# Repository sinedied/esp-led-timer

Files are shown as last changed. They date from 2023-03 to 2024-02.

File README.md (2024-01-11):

# ⏰ esp-led-timer

> 64x32 led matrix timer for conferences with remote WiFi control, based on ESP8266/ESP32.

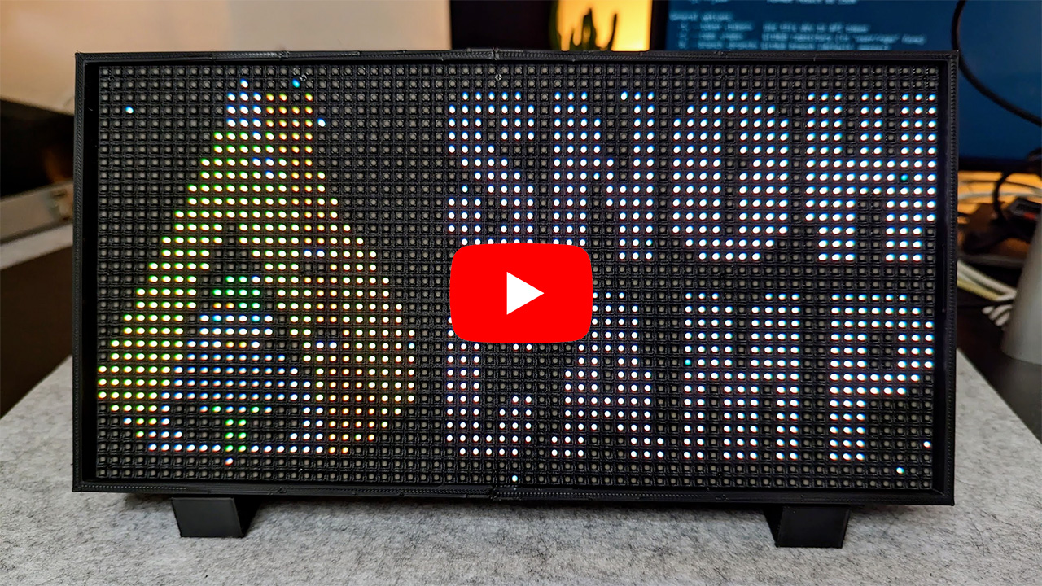
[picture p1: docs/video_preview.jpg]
Demo video (https://youtu.be/CDZh9LY9HXI)


*Note: time countdown is accelerated x100 in the video.*

## Assembly guide

You can find a detailed step-by-step assembly guide [here](./docs/assembly.md).

## Components used
- 64x32 P4 LED Panel [aliexpress](https://aliexpress.com/item/1005004050044228.html)
- ESP32 CH340 Type-C [aliexpress, make sure to pick the right one](https://aliexpress.com/item/1005004616357165.html)
- 2m USB-C cable [aliexpress, make sure to pick the right one](https://aliexpress.com/item/1005004215823904.html)
- 20W USB-C Charger [aliexpress](https://aliexpress.com/item/1005001875465341.html)
- 10cm M-F Dupont Cable 40pin [aliexpress, make sure to pick the right one](https://aliexpress.com/item/1005004073424751.html)
- 10cm F-F Dupont Cable 40pin [aliexpress, make sure to pick the right one](https://aliexpress.com/item/1005004073424751.html)
- 20cm F-F Dupont Cable 40pin [aliexpress, make sure to pick the right one](https://aliexpress.com/item/1005004073424751.html)
- Push button kit [aliexpress](https://aliexpress.com/item/1005005012663073.html)

**Total:** about 30 euros

## Wiring diagram

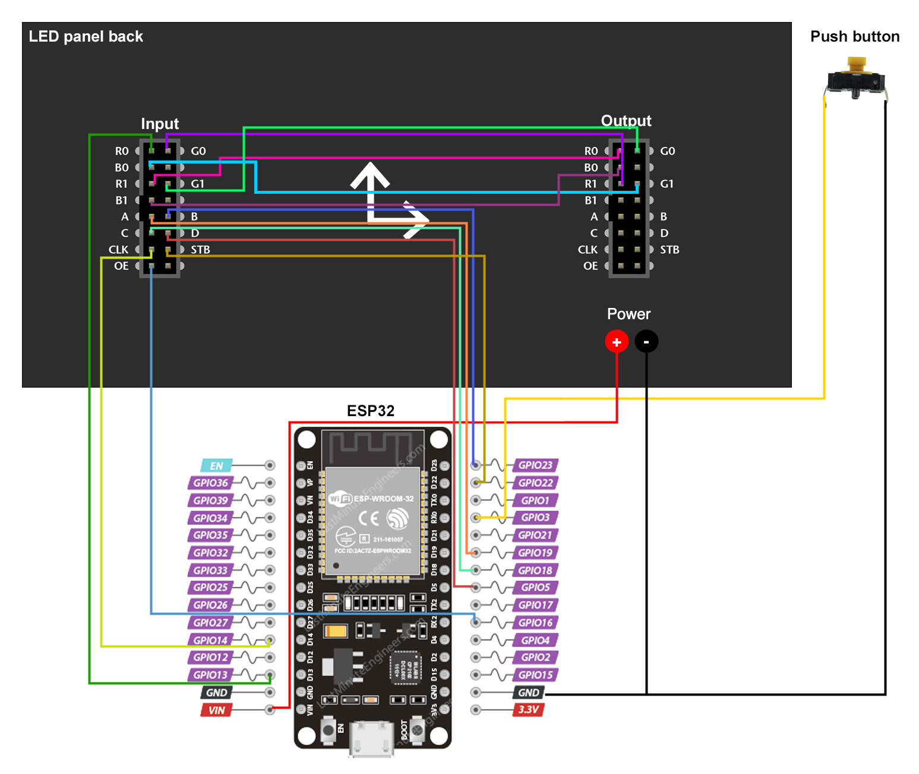
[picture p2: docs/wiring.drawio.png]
Wiring diagram


Connect panel input (PI) and and panel output (PO) like this:

PI | PO
---|---
R1 | R0
G0 | R1
G1 | G0
B0 | G1
B1 | B0

Connect panel input (PI) to the ESP8266 or ESP32 like this:

PI      | ESP8266 GPIO | ESP32 GPIO
--------|--------------|------------
A       |  05 - (D1)   | 19 
B       |  04 - (D2)   | 23 
C       |  15 - (D8)   | 18 
D       |  12 - (D6)   | 5 
STB/LAT |  16 - (D0)   | 22 
P_OE    |  02 - (D4)   | 16 
CLK     |  14 - (D5)   | 14 
R0      |  13 - (D7)   | 13 

Connect push button pins to the ESP8266 or ESP32 like this:

BUTTON | ESP8266 GPIO | ESP32 GPIO
-------|--------------|------------
L      | RX - (D9)    | RX0
R      | GND          | GND

## 3D printed case

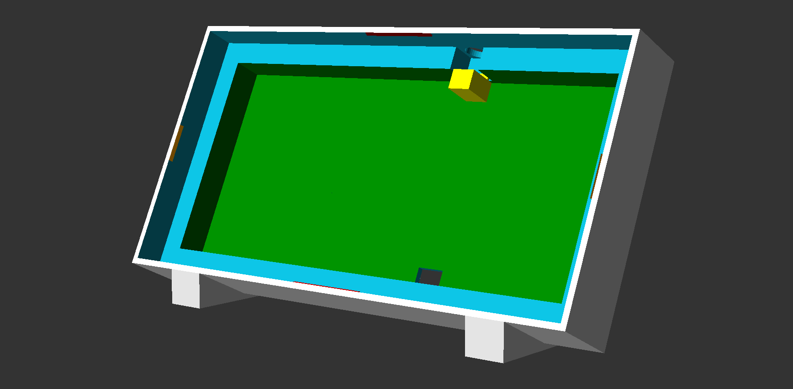
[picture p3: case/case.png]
case preview


You'll find a parameterized case model in `case/case.scad`.

You can customize and compile this file into an STL using [OpenSCAD](https://openscad.org).

I recommend to set `test_print` to true in the customizer ("Other" tab) and first print these test models to test and adapt the `tolerance` value for your printer (higher = more loose fit, smaller = tighter fit).

This model makes use of the BOSL2 library, see [instructions here](https://github.com/revarbat/BOSL2) for how to install it.

## Building project

This project is built using [VS Code](https://code.visualstudio.com/) and [PlatformIO](https://platformio.org/).

Once loaded, Platform IO will download the platform SDK and dependencies automatically, then you'll be able to build and upload the project to your ESP.

> You update the `platformio.ini` file to change the board type and platform, this project is compatible with both ESP8266 and ESP32 boards.

## How to use

- **Push button:** start/stop timer
- **Long press (1s)**: reset timer
- **Double press**: next mode
- **Triple press**: change brightness

Modes cycles between the logo/screensaver and the differents timers.

When the timer is not running, the logo/screensaver will be automatically activated after 5 minutes without touching any button.

### Special commands

- **Hold button for 5s**: enable/disable WiFi AP
- **Hold button for 10s**: reset all settings and reboot
- **5x press**: toggle x100 time acceleration (for demo/testing purposes)

When WiFi is enabled, the device will create an access point with the name "Timer" by default. Connect to it, and you should be presented with a captive portal to control and configure the device.

## Updating bitmaps

To generate the bitmap arrays for images, I used [image2cpp](https://javl.github.io/image2cpp/).
Make sure to set RGB565 format and change the type to `uint16_t static` instead of `const uint16_t`, otherwise the app will crash.

The bitmaps are located in `src/bitmaps.h`.

For drawing the bitmaps I used [PixiArt](https://www.pixilart.com/draw).

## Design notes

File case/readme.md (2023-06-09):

# 3D printed case

case preview

The case of this project is designed to be 3D printed.

You can find ready-to-print STL files in the [stl/](./stl/) folder.
- If you have a 3D printer with a large bed, you can print the case and its support in one piece using the `case_all_nosplit.stl` file.

- Otherwise, you can print the case split in two part and the support separately using the `case_left_part.stl`, `case_right_part.stl` and `case_feet_and_button_lock` files.

The case is designed to be printed with supports, so make sure to enable them in your slicer. Tolerance has been added to the case to make sure the parts fit together nicely, but you'll require a bit of sanding to make it fit perfectly.

To check if the defaut tolerance is good for your printer, you can print the `test_print.stl` file.

### Customizing the case

If you want to customize the case to adjust the tolerance or support angle for example, you need to use [OpenSCAD](https://openscad.org) and install the BOSL2 library. See [instructions here](https://github.com/revarbat/BOSL2) for how to install it.

Then open the `case.scad` file in OpenSCAD and adjust the parameters in the `Customizer` tab. Once you're happy with the result, select `Render` and then `Export as STL...` to export the STL file.

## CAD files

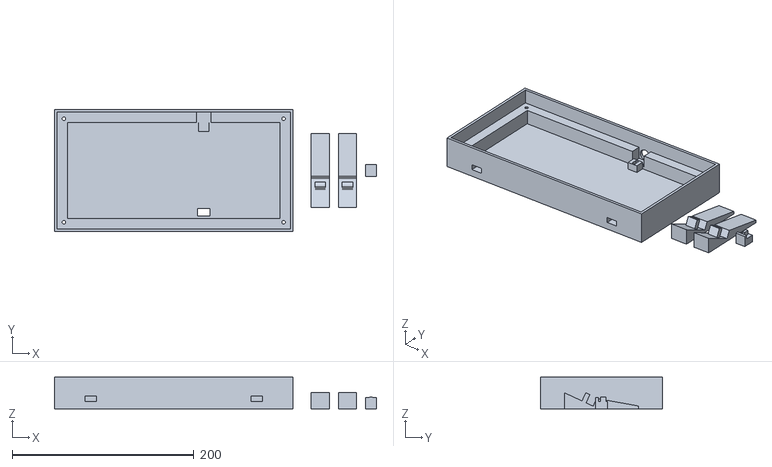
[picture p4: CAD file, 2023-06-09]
case/stl/case_all_nosplit.stl
354.7 x 134.7 x 35.0

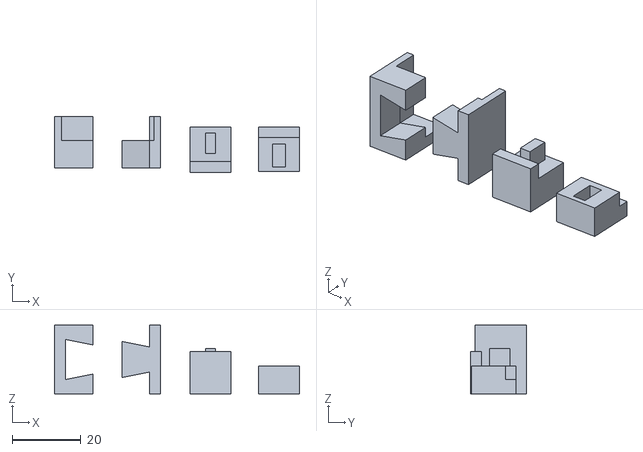
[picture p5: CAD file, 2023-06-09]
case/stl/test_print.stl
71.5 x 16.2 x 20.0

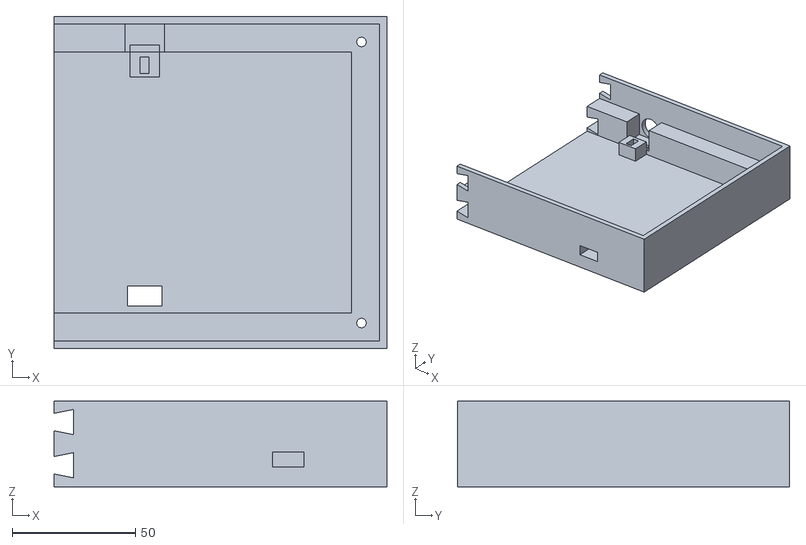
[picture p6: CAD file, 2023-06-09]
case/stl/case_right_part.stl
135.1 x 134.7 x 34.7

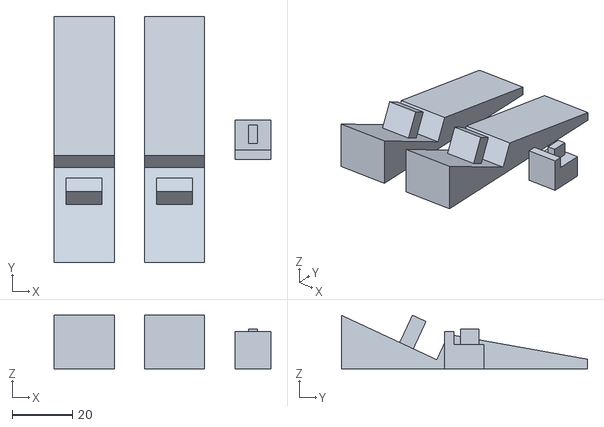
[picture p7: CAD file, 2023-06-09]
case/stl/case_feet_and_button_lock.stl
72.0 x 81.7 x 17.8

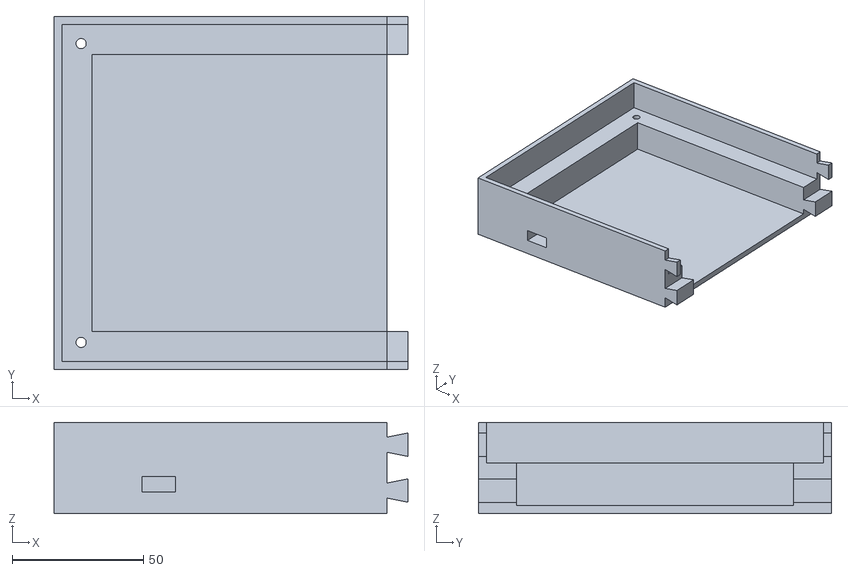
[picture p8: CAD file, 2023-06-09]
case/stl/case_left_part.stl
135.1 x 134.7 x 34.7

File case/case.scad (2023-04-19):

// Compile this file into an STL using OpenSCAD:
// https://openscad.org/

// Requires BOSL2 to be installed, see:
// https://github.com/revarbat/BOSL2
include <BOSL2/std.scad>

/* [Dimensions] ---------------------------------------- */

// LCD panel width
panel_width = 256;

// LCD panel height
panel_height = 128;

// LCD panel depth
panel_depth = 13;

// Wall thickness
wall_width = 3;

// LCD panel back border
inside_border_width = 11.5;

// Space in front of the panel for protection
front_bump = 2;

// Space behind panel for the circuit
circuit_depth = 17;

/* [Hole for usb cable] -------------------------------- */

// Usb hole width
usb_hole_width = 14;

// Usb hole height
usb_hole_height = 8;

// Usb hole centered offset from right side of the panel
usb_hole_offset_x = 95;

// Usb hole centered offset from bottom of the panel
usb_hole_offset_y = 18;

/* [Space and support for button] ---------------------- */

// Push button inner diameter
button_inner_diameter = 11.5;

// Push button outer diameter
button_diameter = 12.8;

// Button switch side width
button_hold_size = 12;

// Space for the button legs and wires
button_side_space = 2;

// Total height of switch + push button (excl. legs)
button_total_height = 12;

// Push button height (excl. switch body)
button_push_height = 8.5;

// Button hole centered offset from right side of the panel
button_offset_x = 95;

// Extra height for button support
button_extra_height = 10;

// Connector width
button_connector_width = 3;

// Connector height
button_connector_height = 6;

// Connector depth
button_connector_depth = 5;

/* [Panel fixation] ------------------------------------ */

// Use screws to fix the panel instead of tabs
use_screws = true;

// Lock tabs thickness
lock_tab_thickness = 0.8;

// Lock tabs base width
lock_tab_size = 20;

// Screw diameter
screw_diameter = 3.2;

// Screw head diameter
screw_head_diameter = 7;

// Screw head depth
screw_head_depth = 5;

// Screw hole position offset from the panel edge
screw_offset = 7;

/* [Angle support] ------------------------------------- */

// Target panel angle
angle = 65;

// Support width
angle_support_width = 20;

// Support extra height
angle_support_extra_height = 50;

// Support min depth
angle_support_min_depth = 3;

// Offset from each side
angle_support_offset_x = 30;

// Connector height
support_connector_height = 5;

// Connector width
support_connector_width = 12;

// Connector depth
support_connector_depth = 10;

/* [Other] --------------------------------------------- */

// Extra space to allow for fit tolerance (reduce for tighter fit)
tolerance = 0.35;

// Fit tolerance for the split parts (reduce for tighter fit)
split_tolerance = 0.25;

// Split case on Y axis instead of Z axis
case_split_y = true;

// Disable case split (if your printer can handle it)
case_no_split = false;

// Left case only
left_case = false;

// Right case only
right_case = false;

// Angle and top button supports only
support_and_button = false;

// Show model with assembled pieces (NOT FOR PRINTING!)
final_view = false;

// Test prints, for checking fit and tolerance value
test_prints = false;

/* [Hidden] */

fudge = .001;
sep = 10;

total_width = panel_width + tolerance*2 + wall_width*2;
total_height = panel_height + tolerance*2 + wall_width*2;
total_depth = panel_depth + circuit_depth + front_bump + wall_width;

panel_hole_width = panel_width + tolerance*2;
panel_hole_height = panel_height + tolerance*2;
panel_hole_depth = panel_depth + tolerance*4 + front_bump;

final_circuit_depth = total_depth - panel_hole_depth + tolerance*2 - wall_width;

final_usb_offset_x = panel_width/2 - usb_hole_offset_x;
final_usb_offset_y = -panel_height/2 + usb_hole_offset_y;
final_usb_depth = wall_width + tolerance*2;

button_hole_width = max(button_hold_size + button_side_space*2, button_diameter + tolerance*2);
button_hole_height = inside_border_width + fudge;
button_hole_depth = button_diameter + tolerance*2;
button_ext_diameter = button_inner_diameter + tolerance*2;

final_button_hole_offset_x = panel_width/2 - button_offset_x;
final_button_hole_offset_y = panel_height/2 + tolerance - inside_border_width + button_hole_height/2 - fudge;
final_button_hole_offset_z = total_depth - panel_hole_depth + tolerance*2 - button_hole_depth + fudge;

button_holder_width = button_hold_size;
button_holder_height = button_hole_height - button_push_height + button_extra_height;
button_holder_depth = final_circuit_depth;
button_holder_offset_y = -button_holder_height/2 + panel_hole_height/2 - button_push_height;

button_support_height = button_total_height - button_push_height;

button_support_depth = button_holder_depth - button_hole_depth + (button_diameter - button_hold_size);
button_support_cut_depth = button_holder_depth - button_support_depth;

angle_height= total_depth * sin(angle);
angle_depth = sqrt(pow(total_depth, 2) - pow(angle_height, 2));
angle_support_height = angle_height + angle_support_extra_height;
angle_support_depth = angle_depth + angle_support_min_depth;
angle_support_offset_y = angle_support_extra_height/2;

support_left_offset_x = angle_support_width/2 - total_width/2 + angle_support_offset_x;
support_right_offset_x = -angle_support_width/2 + total_width/2 - angle_support_offset_x;
connector_y_offset = angle_support_height/2 - angle_height;

$fa = 10;
$fs = .4;
$vpr = [
  final_view ? 85 : 22.5,
  0,
  final_view ? 65 : 0
];
$vpd = final_view ? 700 : 800;
$vpt = final_view ? [0, 0, total_height/2] : [(angle_support_width + sep*5 + button_holder_width)/2, 0, 0];

// ----------------------------------------------------------

module triangle(size, rot = 0) {
  w = size[0];
  h = size[1];
  d = size[2];
  points = [
    [0, 0],
    [0, d],
    [h, 0],
  ];
  path = [
    [0, 1, 2]
  ];
  rotate([90, 0, 270 - rot])
  translate([-h/2, -d/2, -w/2])
  linear_extrude(w) { 
    polygon(points, path);
  }
}

module lock_tab(width = true, mirror = false) {
  points = [
    [0, 0],
    [0, front_bump],
    [lock_tab_thickness, 0],
  ];
  path = [
    [0, 1, 2]
  ];
  if (width) {
    tab_size = lock_tab_size;
    // tab_size = panel_hole_width;
    color("red")
    scale([1, mirror ? -1 : 1, 1])
    translate([0, 0, front_bump/2])
    rotate([90, 0, -90])
    translate([-lock_tab_thickness/2, -front_bump/2, -tab_size])
    linear_extrude(tab_size*2) { 
      polygon(points, path);
    }
  } else {
    tab_size = lock_tab_size;
    // tab_size = panel_hole_height;
    color("orange")
    scale([mirror ? -1 : 1, 1, 1])
    translate([0, 0, front_bump/2])
    rotate([90, 0, 0])
    translate([-lock_tab_thickness/2, -front_bump/2, -tab_size/2])
    linear_extrude(tab_size) { 
      polygon(points, path);
    }    
  }
}

module lock_tabs() {
  // Top tab
  translate([0, -lock_tab_thickness/2 + panel_hole_height/2 + fudge, total_depth - front_bump])
  lock_tab(true, false);
  // Bottom tab
  translate([0, lock_tab_thickness/2 + -panel_hole_height/2 - fudge, total_depth - front_bump])
  lock_tab(true, true);
  // Left tab
  translate([lock_tab_thickness/2 - panel_hole_width/2 - fudge, 0, total_depth - front_bump])
  lock_tab(false, false);
  // Right tab
  translate([-lock_tab_thickness/2 + panel_hole_width/2 + fudge, 0, total_depth - front_bump])
  lock_tab(false, true);
}

module screws_hole() {
  inner_diameter = screw_diameter + tolerance*2;
  outer_diameter = screw_head_diameter + tolerance*2;
  width_offset = total_width/2 - wall_width - tolerance - screw_offset;
  height_offset = total_height/2 - wall_width - tolerance - screw_offset;

  // Top left
  translate([-width_offset, height_offset, 0]) {
    union() {
      cylinder(total_depth*2 + 1, d=inner_diameter, center=true);

      translate([0, 0, screw_head_depth/2 - fudge])
      cylinder(screw_head_depth, d=outer_diameter, center=true);
    }
  }

  // Top right
  translate([width_offset, height_offset, 0]) {
    union() {
      cylinder(total_depth*2 + 1, d=inner_diameter, center=true);

      translate([0, 0, screw_head_depth/2 - fudge])
      cylinder(screw_head_depth, d=outer_diameter, center=true);
    }
  }

  // Bottom left
  translate([-width_offset, -height_offset, 0]) {
    union() {
      cylinder(total_depth*2 + 1, d=inner_diameter, center=true);

      translate([0, 0, screw_head_depth/2 - fudge])
      cylinder(screw_head_depth, d=outer_diameter, center=true);
    }
  }

  // Bottom right
  translate([width_offset, -height_offset, 0]) {
    union() {
      cylinder(total_depth*2 + 1, d=inner_diameter, center=true);

      translate([0, 0, screw_head_depth/2 - fudge])
      cylinder(screw_head_depth, d=outer_diameter, center=true);
    }
  }
}

module button_hole() {
  diff_diameter = button_hole_depth - button_ext_diameter;
  union() {
    // Button space
    translate([0, -0.5, button_hole_depth/2 + 0.5])
    cube([button_hole_width, button_hole_height + 1, button_hole_depth + 1], center = true);
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

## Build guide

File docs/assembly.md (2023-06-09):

# Assembly guide

This is a step-by-step guide to assemble the project.
After following these steps, you will have a fully working device looking like this:

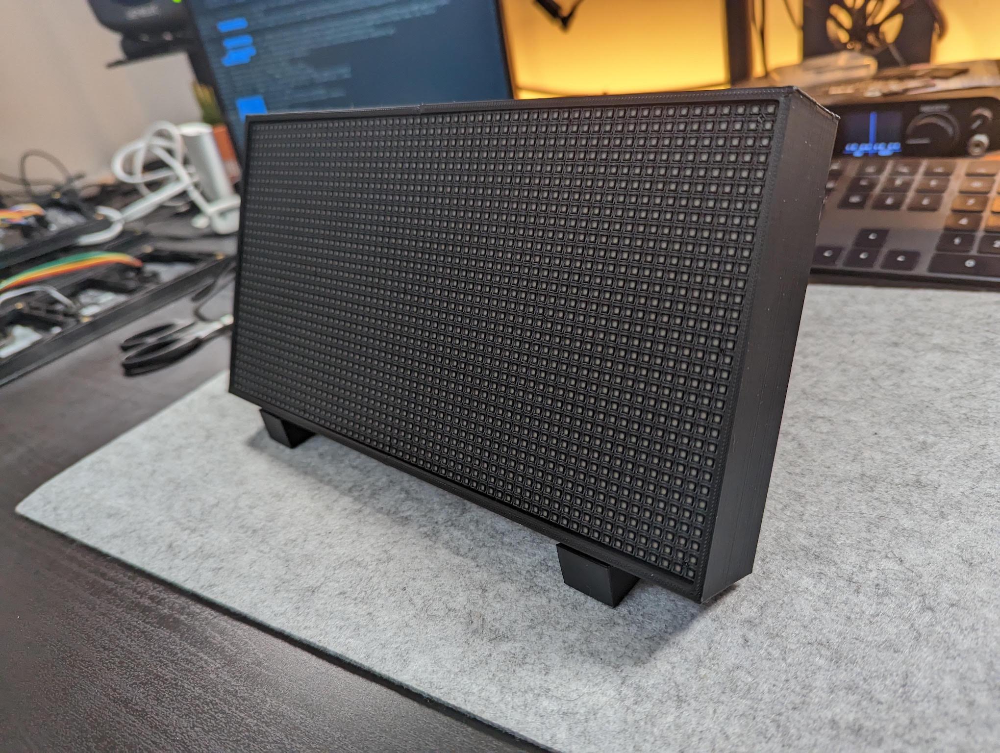
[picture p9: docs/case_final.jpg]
Final result


## Parts and tools needed

Not counting the tools and 3D printed parts, this project costs about 30 euros in parts.

- 1x 64x32 P4 LED Panel [aliexpress](https://aliexpress.com/item/1005004050044228.html)
- 1x ESP32 CH340 Type-C [aliexpress, make sure to pick the right one](https://aliexpress.com/item/1005004616357165.html)
- 1x 2m USB-C cable [aliexpress, make sure to pick the right one](https://aliexpress.com/item/1005004215823904.html)
- 1x 20W USB-C Charger [aliexpress](https://aliexpress.com/item/1005001875465341.html)
- 5x 20cm F-F Dupont Cable 40pin [aliexpress, make sure to pick the right one](https://aliexpress.com/item/1005004073424751.html)
- 8x 10cm F-F Dupont Cable 40pin [aliexpress, make sure to pick the right one](https://aliexpress.com/item/1005004073424751.html)
- 4x 10cm M-F Dupont Cable 40pin [aliexpress, make sure to pick the right one](https://aliexpress.com/item/1005004073424751.html)
- 1x Push button kit [aliexpress](https://aliexpress.com/item/1005005012663073.html)
- 4x M3 20mm screws
- Soldering iron
- Soldering tin
- Electrical tape
- Double sided tape
- Screwdriver

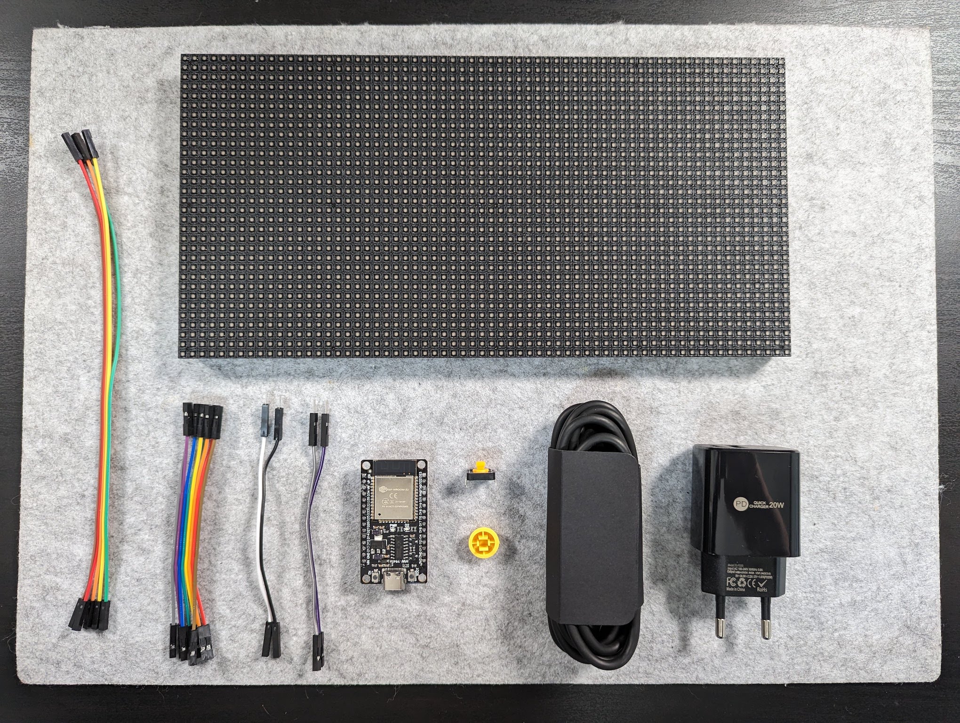
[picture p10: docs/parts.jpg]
Parts


You'll also need to print [the case](../case/) using a 3D printer. If you don't have a 3D printer, you can ask a friend who have one or find a fab lab near your home.

## Soldering the panel power

We'll start by soldering the panel power wires to 10cm M-F Dupont Cables.
Pick 2 10cm M-F Dupont Cables and bend the pins like this:

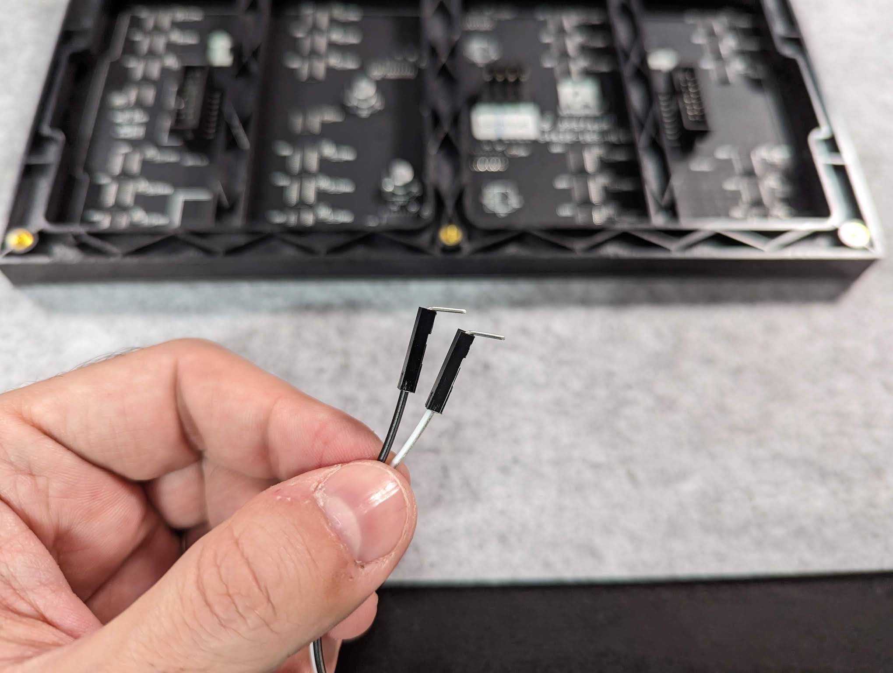
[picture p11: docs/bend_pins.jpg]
Bend pins


Pick the LED panel, and make sure to position it with the arrows pointing up:

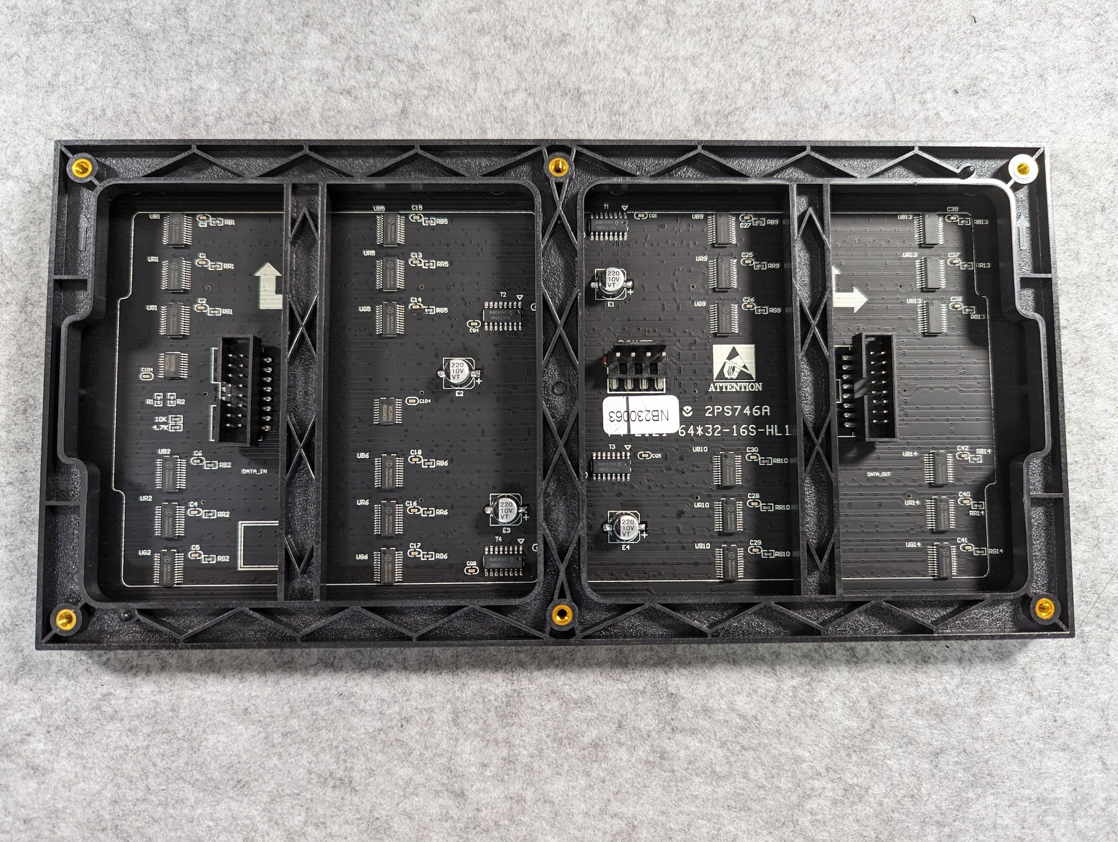
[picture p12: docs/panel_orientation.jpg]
Panel orientation


Then, solder the cables to the panel power wires. The negative wire is the one on the right, and the positive wire is the one on the left:

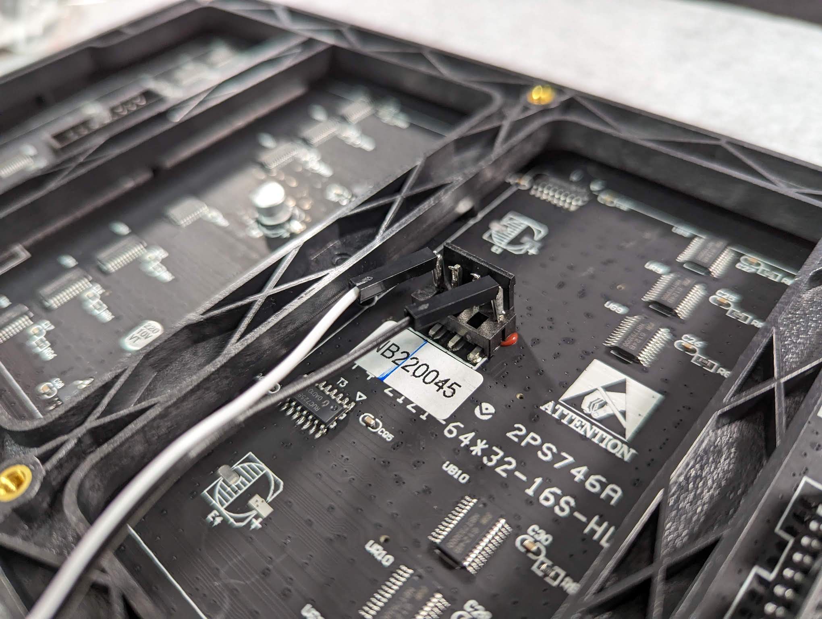
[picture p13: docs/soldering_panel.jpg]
Soldering panel power


## Soldering the button switch

Next we'll solder the button switch to the 10cm M-F Dupont Cables.
Pick 2 10cm M-F Dupont Cables and solder it to the button switch pins on a same side (left or right, it doesn't matter):

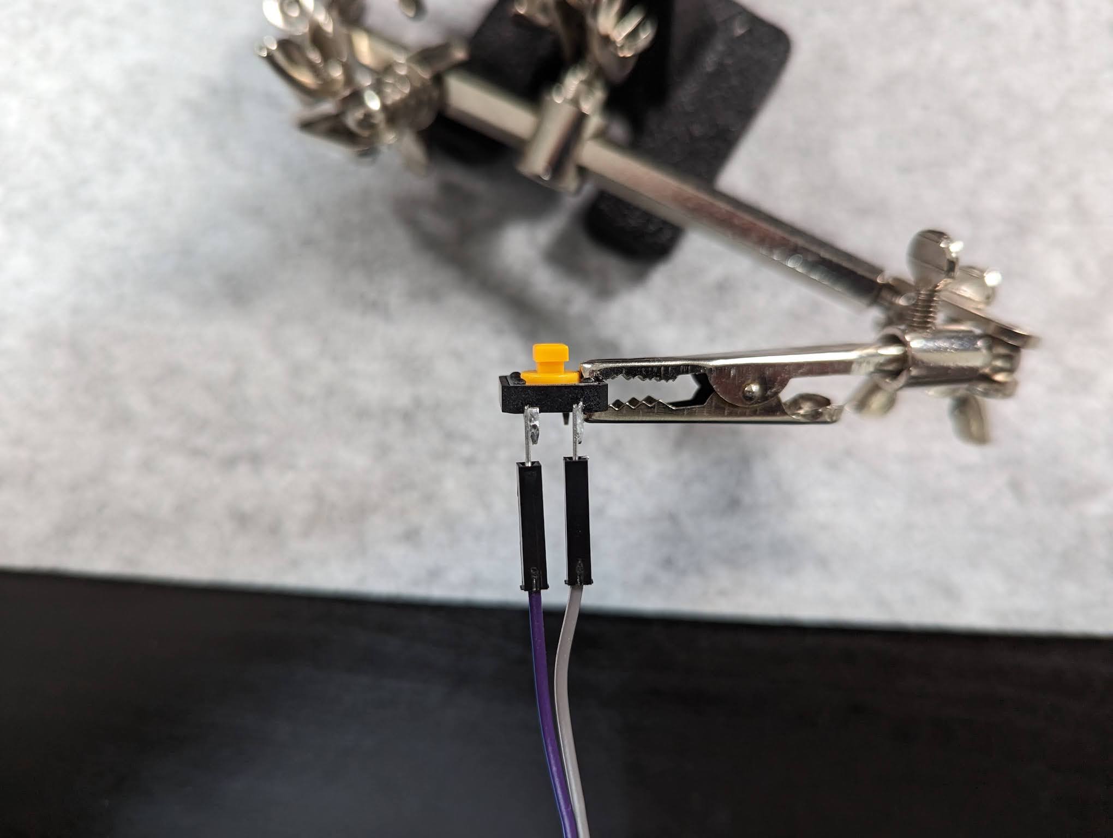
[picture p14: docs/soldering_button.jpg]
Soldering button switch


Position the cable pin and the button pin so that they are aligned side by side, to avoid making a bulge as it would make it harder to fit in the case later.

(And try to do a better job than me at soldering 😆)

## Wiring the panel

Here is the complete wiring diagram:

Complete wiring diagram

We'll first wire the panel inputs (PI) and outputs (PO) together using the 20cm F-F Dupont cables.
Connect panel input (PI) and and panel output (PO) following this table:

PI | PO
---|---
R1 | R0
G0 | R1
G1 | G0
B0 | G1
B1 | B0

The result should look like this:

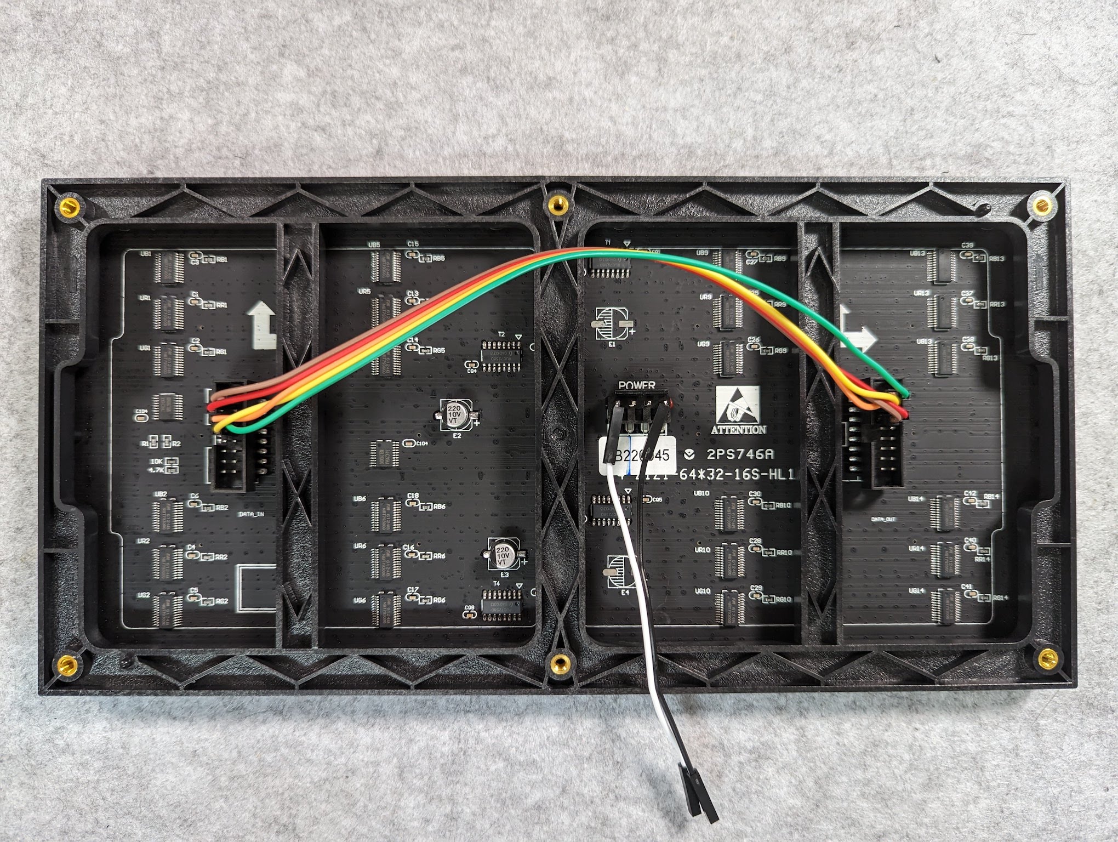
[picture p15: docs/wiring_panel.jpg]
Wiring panel result


## Wiring the ESP32

Pick the 10cm F-F Dupont Cables and connect the ESP32 to the panel following this table:

PI      | ESP32 GPIO
--------|-------------
A       | 19 
B       | 23 
C       | 18 
D       | 5 
STB/LAT | 22 
P_OE    | 16 
CLK     | 14 
R0      | 13 

It's easier to first all the cables to the panel, then to the ESP32. After you're done, connect the button switch to the ESP32:

BUTTON | ESP32 GPIO
-------|-------------
Pin 1  | RX0
Pin 2  | GND

You should end up with something like this:

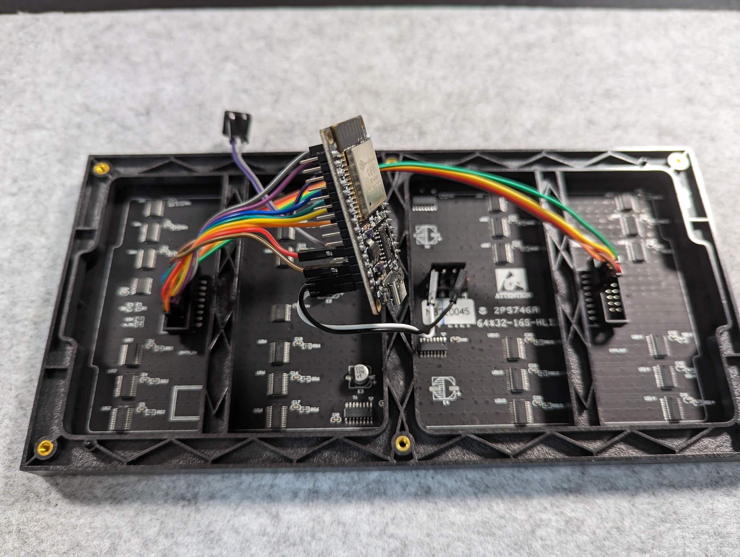
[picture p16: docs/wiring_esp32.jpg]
Wiring ESP32 result


## Uploading the firmware and testing

At this point it is a good idea to test the wiring before going further. To do so, you'll need to upload the firmware to the ESP32.

The easiest it to install [VS Code](https://code.visualstudio.com/) and the [PlatformIO](https://platformio.org/) extension. Follow the [installation guide](https://platformio.org/install/ide?install=vscode) to install both.

Open VS Code and select `Clone Repository`:

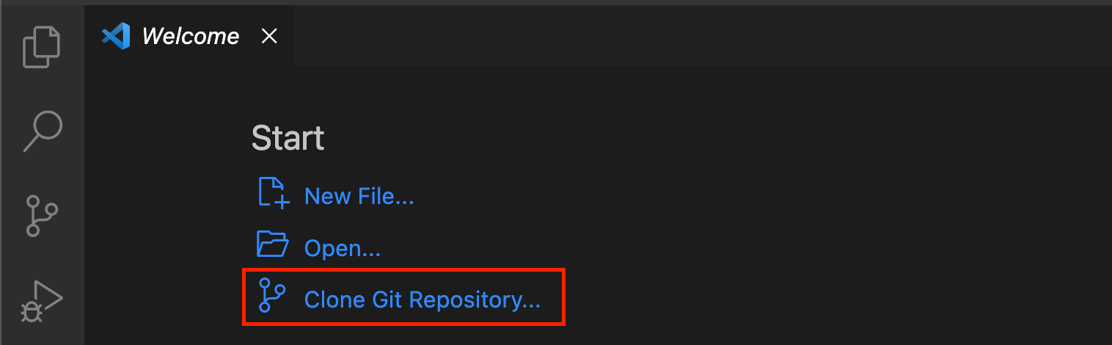
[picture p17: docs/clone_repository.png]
Clone repository


Enter the repository URL `https://github.com/sinedied/esp-led-timer` and select a folder to clone it to. After cloning, select `Open` when prompted.

PlatformIO will take some time to initialize the project and install the dependencies. Once it's done, connect the ESP32 to your computer using the USB-C cable and select the `Upload` button in the status bar:

Upload button in VS Code status bar

The firmware will first compile, then upload to the ESP32. If everything goes well, you should see the following message in the terminal:

```
TODO
```

If your wiring is correct, the LED panel will light up and display the visual manual. Push the button to switch to the timer mode and check that the timer is working.

## Fixing the ESP32 to the case

Now that we know everything is working, we can complete the assembly.

Add some electrical tape on the panel in the top left corner of the section where the ESP32 will be placed, to avoid short circuits:

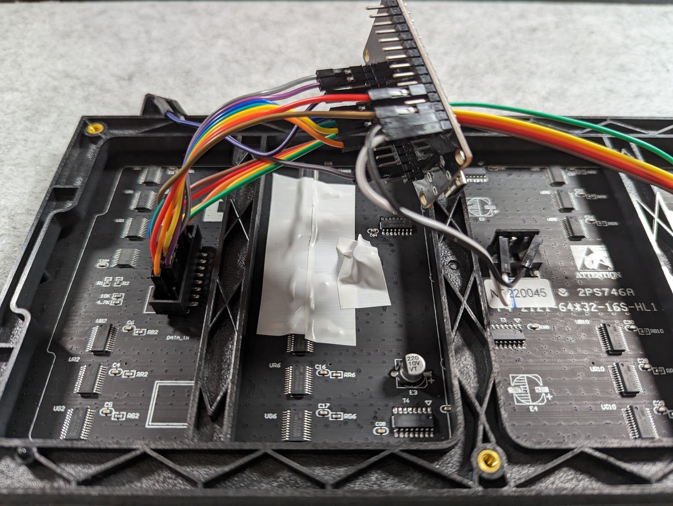
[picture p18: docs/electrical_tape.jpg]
Electrical tape


Then, add some double sided tape on the ESP32 processor and fix it to the case over the electrical tape we just added:

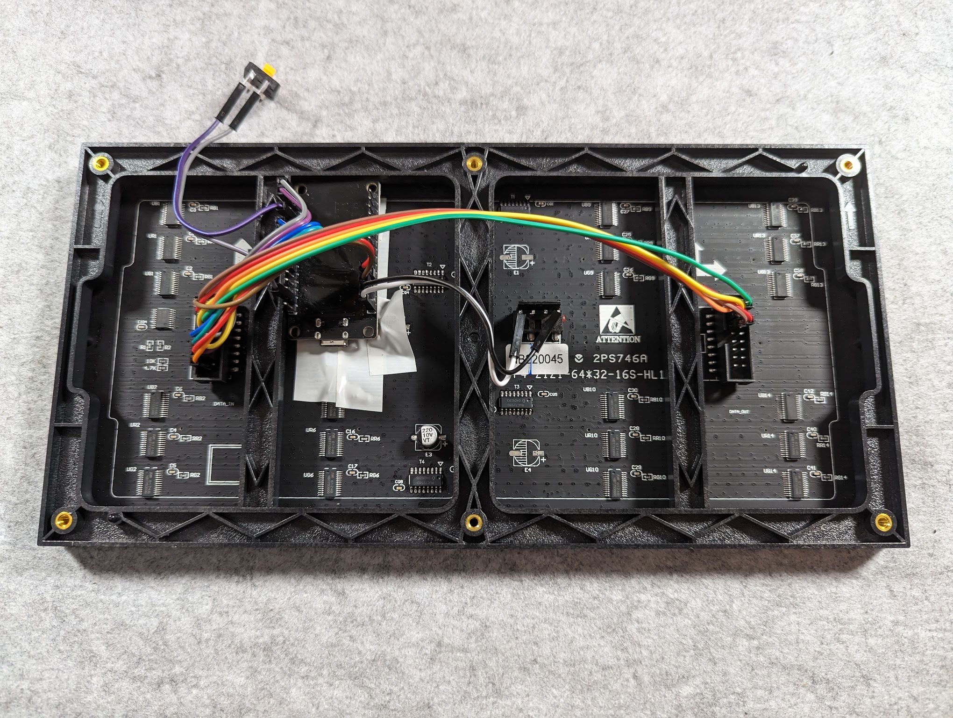
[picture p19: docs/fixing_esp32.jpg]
Fixing ESP32 to the case


Flatten the cables a bit to make it easier to fit in the case.

## 3D Printing the case

The next step is to 3D print the case. You can find the STL files and instructions for printing the case [here](../case/readme.md).

If you printed the case in 2 separate parts, you'll need to assemble the left and right parts together. Don't force too much or you'll break the plastic. If it doesn't fit, try to sand the parts a bit. The fit should be tight so the parts doesn't move, but must fit with only a bit of force.

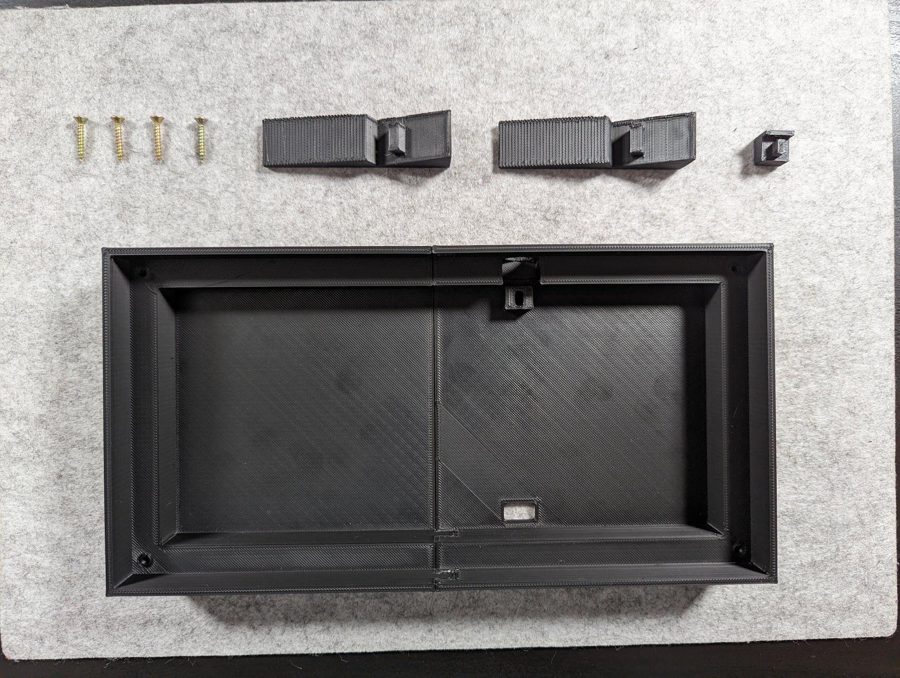
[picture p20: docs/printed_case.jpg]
3D printed case and screws


## Assembling the case

It's time to assemble the case and the electronics.

1. Pass the cables through the hole in the case, from the outside to the inside, and position the button cap from the inside:

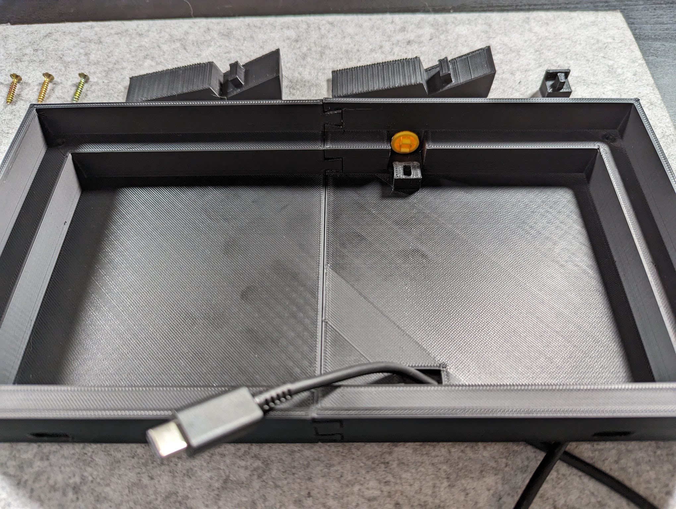
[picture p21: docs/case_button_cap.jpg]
Placing the cable and button cap
   

  The button cap should be sliding without difficulty. If it doesn't, remove it and try to sand the hole a bit.

2. Plug the USB-C cable to the ESP32 without leaving too much cable inside the case.

3. Place the button switch inside the button cap, with the 2 connected pins on the left side of the support:

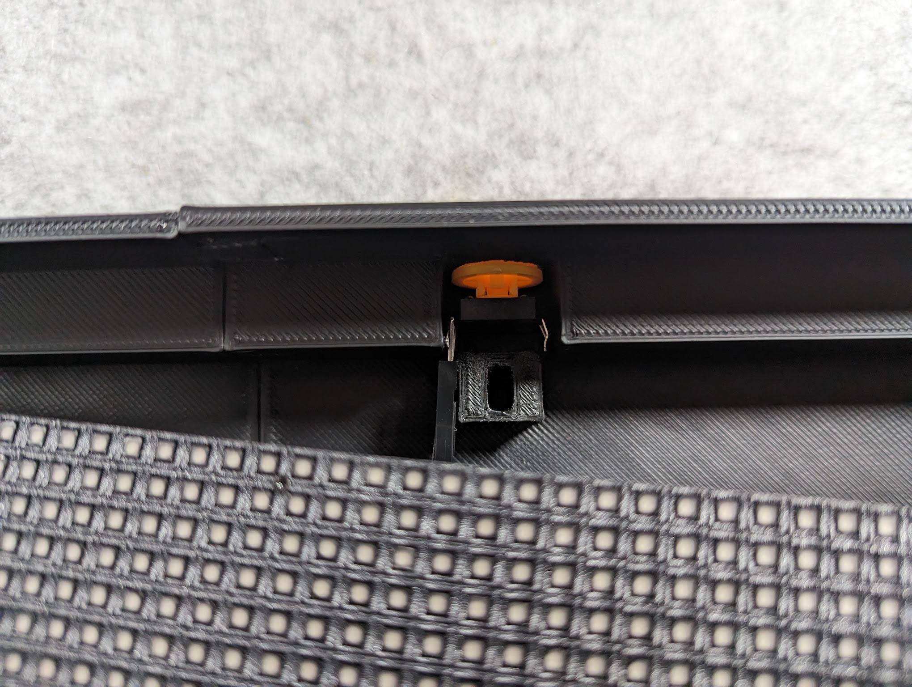
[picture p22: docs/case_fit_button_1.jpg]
Fit the button switch in the case
   

4. Insert the 3D printed button holder with the tab sliding just under the button switch:

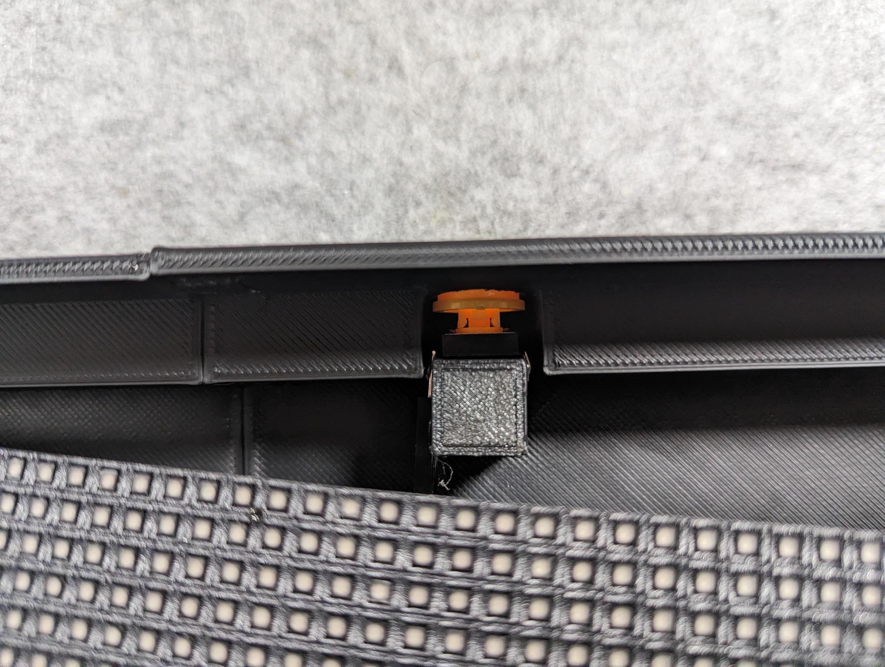
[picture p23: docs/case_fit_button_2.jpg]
Fix the button holder
   

   Make sure the button switch works fine and doesn't get stuck.

5. Place the LED panel in the case, while making sure no cables are pinched. Hold the case and panel together to return it and access the screw holes on the back. Screw the panel to the case using the 4 screws.

6. Insert the removable support feet in the bottom of the case.

You're done! 🎉

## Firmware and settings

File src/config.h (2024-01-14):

#ifndef __CONFIG_H
#define __CONFIG_H

#include <FS.h>
#include <LittleFS.h>
#include <Arduino.h>

#define CONFIG_FILE               "/config"
#define MAX_TIMERS                3
#define DEFAULT_USE_WIFI          false
#define DEFAULT_USE_SCREENSAVER   false
#define DEFAULT_USE_AP            true
#define DEFAULT_SCREENSAVER_TIME  5      // in minutes
#define DEFAULT_HOSTNAME          "Timer"
#define DEFAULT_PASSWORD          ""
#define DEFAULT_BRIGHTNESS        127
#define DEFAULT_TIMER_COUNT       2
#define DEFAULT_TIMERS            { { 45, 15, 10, 5 }, { 20, 10, 5, 2 }, { 10, 5, 2, 1 } }

struct timer_settings_t {
  uint8_t duration;   // in minutes
  uint8_t warn1;      // remaining time in minutes
  uint8_t warn2;      // remaining time in minutes
  uint8_t warn3;      // remaining time in minutes
};

struct config_t {
  bool use_wifi = DEFAULT_USE_WIFI;
  bool use_screensaver = DEFAULT_USE_SCREENSAVER;
  bool use_ap = DEFAULT_USE_AP;
  char hostname[32] = DEFAULT_HOSTNAME;
  char password[32] = DEFAULT_PASSWORD;
  uint32_t screensaver_time = DEFAULT_SCREENSAVER_TIME;
  uint8_t brightness = DEFAULT_BRIGHTNESS;
  uint8_t timer_count = DEFAULT_TIMER_COUNT;
  timer_settings_t timers[MAX_TIMERS] = DEFAULT_TIMERS;
};

extern config_t config;

void saveConfig();
void loadConfig();
void resetConfig();

#endif // __CONFIG_H

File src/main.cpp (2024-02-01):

#include <Arduino.h>
#include <OneButton.h>
#include "types.h"
#include "display.h"
#include "bitmaps.h"
#include "extra.h"
#include "config.h"
#include "network.h"

// #define DEBUG_SIM   1       // Simulate display on serial
#define DEBUG_FAST  0       // Accelerate time x100 for debug
#define STOP_AT     -9*60   // Stop overtime timer X seconds
#define HOLD_CONFIG 5       // Hold button for X seconds to enter config mode
#define HOLD_RESET  10      // Hold button for X seconds to reset all settings

#ifdef ESP32
  #define P_BUTTON    RX    // Pin for the hardware button
  #define SKIP_UPDATE 120   // Update every n cycles
#elif ESP8266
  #define P_BUTTON    D9    // Pin for the hardware button
  #define SKIP_UPDATE 60    // Update every n cycles
#endif

#ifdef DEBUG_SIM
  #define DEBUG_SIM_PRINTF(...)   Serial.printf(__VA_ARGS__)
  #undef SKIP_UPDATE
  #ifdef ESP32
    #define SKIP_UPDATE 1200
  #elif ESP8266
    #define SKIP_UPDATE 600
  #endif
#else
  #define DEBUG_SIM_PRINTF(...)
#endif


// TODO: use system_get_time for best precision
Ticker time_ticker;
Ticker screensaver_ticker;

uint16_t progress_colors[] = {
  COLOR_GREEN,
  COLOR_YELLOW,
  COLOR_ORANGE,
  COLOR_RED,
  COLOR_MAGENTA
};

OneButton button = OneButton(P_BUTTON);
bool fast_time = DEBUG_FAST;
bool need_update = true;
bool has_switched_wifi = false;
uint16_t skip_update = 0;
int8_t prev_mode = MODE_UNDEF;
uint8_t progress_bar_warn[3];
uint8_t cycle = 0;
unsigned long press_start;
message_t message;
app_state_t state;
uint32_t timer_duration = 0;
unsigned long timer_start_time = 0;
unsigned int elapsed_time = 0; // in seconds
int8_t async_next_mode = state.cur_mode;
bool async_save_reboot = false;

static void nextMode(int8_t mode);

static void resetScreensaverTimer() {
  screensaver_ticker.detach();
  if (config.use_screensaver && state.cur_mode != MODE_LOGO && !state.timer_started) {
    screensaver_ticker.once(config.screensaver_time * 60, []() -> void {
      prev_mode = state.cur_mode;
      nextMode(MODE_LOGO);
    });
  }
}

void computeProgressBarWarnZones() {
  timer_settings_t timer = config.timers[state.cur_mode - 1];
  progress_bar_warn[0] = (timer.duration - timer.warn1) * DISPLAY_WIDTH / timer.duration;
  progress_bar_warn[1] = (timer.duration - timer.warn2) * DISPLAY_WIDTH / timer.duration;
  progress_bar_warn[2] = (timer.duration - timer.warn3) * DISPLAY_WIDTH / timer.duration;
}

static void resetTimer() {
  if (state.cur_mode >= MODE_TIMER_N) {
    state.cur_time = config.timers[state.cur_mode - 1].duration * 60;
    elapsed_time = 0;
    computeProgressBarWarnZones();
  }

  state.timer_started = false;
  time_ticker.detach();
  resetScreensaverTimer();
}

static void startTimer() {
  if (state.cur_mode >= MODE_TIMER_N && !state.timer_started) {
    state.timer_started = true;
    timer_duration = config.timers[state.cur_mode - 1].duration * 60;
    timer_start_time = millis();

    time_ticker.attach(fast_time ? 0.01 : 0.25, []() -> void {
      if (fast_time) {
        --state.cur_time;
      } else {
        state.cur_time = timer_duration - (millis() - timer_start_time) / 1000 - elapsed_time;
      }

      if (state.cur_time <= STOP_AT) {
        resetTimer();
      }
    });
  }
}

static void stopTimer() {
  if (state.cur_mode >= MODE_TIMER_N && state.timer_started) {
    state.timer_started = false;
    time_ticker.detach();
    // Save already elapsed time
    elapsed_time += (millis() - timer_start_time) / 1000;
  }
}

static void checkForHoldActions() {
  uint32_t press_since = (millis() - press_start) / 1000;

  if (!has_switched_wifi && press_since > HOLD_CONFIG) {
    has_switched_wifi = true;

    // On ESP32, display need to be disabled during wifi activation
    displayUpdateEnable(false);
    enableWifi(!config.use_wifi);
    displayUpdateEnable(true);

    strcpy(message.title, "WIFI");
    sprintf(message.line1, "AP %s", config.use_wifi ? "on" : "off");
    strcpy(message.line2, config.use_wifi ? getIP().toString().c_str() : "");

    prev_mode = state.cur_mode;
    message.start_time = millis();
    nextMode(MODE_MESSAGE);
  }

  if (press_since > HOLD_RESET) {
    Serial.println("Resetting all settings");
    resetConfig();
    resetWifi();
    delay(1000);
    ESP.restart();
  }
}

static void nextMode(int8_t mode = MODE_UNDEF) {
  if (mode != MODE_UNDEF && (mode < MODE_MESSAGE || mode > MAX_TIMERS)) {
    Serial.printf("Invalid mode: %d\n", mode);
    return;
  }

  if (state.cur_mode == MODE_MESSAGE || (prev_mode != MODE_UNDEF && mode >= MODE_TIMER_N)) {
    state.cur_mode = prev_mode;
    prev_mode = MODE_UNDEF;
  } else {
    state.cur_mode = mode == MODE_UNDEF ? (state.cur_mode + 1) % (config.timer_count + 1) : mode;
  }

  resetTimer();
  async_next_mode = state.cur_mode;
  need_update = true;
  skip_update = 0;
  Serial.printf("Set mode: %d\n", state.cur_mode);
}

static void onPush() {
  if (state.cur_mode < MODE_TIMER_N) {
    nextMode(MODE_TIMER_N);
    return;
  }

  if (state.timer_started) {
    stopTimer();
  } else {
    startTimer();
  }

  resetScreensaverTimer();
}

void drawBitmap(uint8_t x, uint8_t y, const uint16_t* bitmap, uint8_t w, uint8_t h) {
 int pixel = 0;
 for (int yy = 0; yy < h; yy++) {
   for (int xx = 0; xx < w; xx++) {
     display.drawPixel(xx + x , yy + y, bitmap[pixel]);
     pixel++;
   }
 }
}

void drawProgressbar(timer_settings_t& timer ) {
  int curr = DISPLAY_WIDTH - state.cur_time * DISPLAY_WIDTH / timer.duration / 60;
  int warn1 = (timer.duration - timer.warn1) * DISPLAY_WIDTH / timer.duration;
  int warn2 = (timer.duration - timer.warn2) * DISPLAY_WIDTH / timer.duration;
  int warn3 = (timer.duration - timer.warn3) * DISPLAY_WIDTH / timer.duration;

  if (state.cur_time > 0) {
    display.writeFillRect(0, 28, warn1, 4, progress_colors[0]);
    display.writeFillRect(warn1, 28, warn2 - warn1, 4, progress_colors[1]);
    display.writeFillRect(warn2, 28, warn3 - warn2, 4, progress_colors[2]);
    display.writeFillRect(warn3, 28, DISPLAY_WIDTH - warn3, 4, progress_colors[3]);
    display.writeFillRect(0, 28, curr, 4, COLOR_BLACK);

    // Draw white triangle
    display.writeFastHLine(curr - 1, 26, 3, COLOR_WHITE);
    display.writePixel(curr, 27, COLOR_WHITE);
  } else {
    cycle = (cycle + 1) % (SKIP_UPDATE);
    float b = sin(PI * cycle / (SKIP_UPDATE));  // ~1s cycle
    uint16_t color = display.color565(223 * b, 0, 191 * b);

    // If time negative, flash message every second
    display.writeFillRect(0, 25, 4, 4, color);
    display.writeFillRect(60, 25, 4, 4, color);

    display.setTextColor(color);
    display.setTextSize(1);
    display.setCursor(5, 23);
    display.print("TIME OVER");
  }
}

void showTimer() {
  if (skip_update > 0) {
    skip_update--;
    return;
  }

  skip_update = SKIP_UPDATE; 
  display.fillScreen(COLOR_BLACK);

  timer_settings_t timer = config.timers[state.cur_mode - 1];
  int cur_min = state.cur_time / 60;
  uint16_t cur_color = progress_colors[0];
  
  if (state.cur_time <= 0) {
    cur_color = progress_colors[4];
  } else if (cur_min <= timer.warn3) {
    cur_color = progress_colors[3];
  } else if (cur_min <= timer.warn2) {
    cur_color = progress_colors[2];
  } else if (cur_min <= timer.warn1) {
    cur_color = progress_colors[1];
  }

  display.setTextColor(cur_color);
  display.setTextSize(2);
  display.setCursor(27, 6);
  display.print(":");
  display.setCursor(6, 6);
  display.printf("%02d", abs(cur_min));
  display.setCursor(36, 6);
  display.printf("%02d", abs(state.cur_time % 60));

  if (state.cur_time < 0) {
    display.writeFillRect(0, 12, 4, 2, cur_color);
  }

  drawProgressbar(timer);
  display.showBuffer();
  DEBUG_SIM_PRINTF("Time: %02d:%02d\n", cur_min, abs(state.cur_time % 60));
}

void showLogo() {
  if (state.cur_mode == MODE_LOGO) {
    if (need_update) {
      // Randomize snowflakes
      for (uint8_t i = 0; i < SNOWFLAKE_COUNT; i++) {
        newSnowFlake(snowflakes[i]);
      }
      need_update = false;
    }

    if (skip_update > 0) {
      skip_update--;
      return;
    }

    skip_update = SKIP_UPDATE;
    drawBitmap(0, 0, bmp_snowcamp_64x32, 64, 32);
    cycle++;

    for (uint8_t i = 0; i < SNOWFLAKE_COUNT; i++) {
      if (snowflakes[i].y >= 0) {
        display.drawPixelRGB888(snowflakes[i].x, snowflakes[i].y, snowflakes[i].b * .5, snowflakes[i].b, snowflakes[i].b);
      }
      if ((cycle % snowflakes[i].s) == 0) {
        snowflakes[i].y++;
      }
      if (snowflakes[i].y == 32) {
        newSnowFlake(snowflakes[i]);
      }
    }

    display.showBuffer();
    DEBUG_SIM_PRINTF("Animated logo\n");
  } else {
    if (need_update) {
      drawBitmap(0, 0, bmp_snowcamp_64x32, 64, 32);
      display.showBuffer();
      DEBUG_SIM_PRINTF("Logo\n");
    }
    need_update = false;
  }
}

void showInfo() {
  if (need_update) {
    drawBitmap(0, 0, bmp_manual_64x32, 64, 32);
    display.showBuffer();
    DEBUG_SIM_PRINTF("Info\n");
  }
  need_update = false;
}

void showMessage() {
  uint32_t since = (millis() - message.start_time) / 1000;

  if (since > message.duration_sec) {
    Serial.println("Message timeout");
    nextMode();
    return;
  } else if (need_update) {
    display.fillScreen(COLOR_BLACK);
    display.setTextColor(COLOR_WHITE);
    display.setTextSize(1);
    display.setCursor(0, 0);
    display.print(message.title);
    display.setTextColor(COLOR_YELLOW);
    display.setCursor(0, 10);
    display.print(message.line1);
    display.setCursor(0, 20);
    display.print(message.line2);
    display.showBuffer();
    DEBUG_SIM_PRINTF("Message: %s\n%s\n%s\n", message.title, message.line1, message.line2);
  }

  need_update = false;
}

void setup() {
  Serial.begin(9600);
  Serial.println();

  loadConfig();

  state.brightness = config.brightness;
  initDisplay(state.brightness);

  pinMode(P_BUTTON, INPUT);
  button.attachClick(onPush);
  button.attachDoubleClick([]() { nextMode(); });
  button.attachMultiClick([]() {
    int clicks = button.getNumberClicks();
    if (clicks == 3) {
      state.brightness = (state.brightness + 64) % 256;
      display.setBrightness(state.brightness);
    } else if (clicks == 5) {
      fast_time = !fast_time;
    }
    resetScreensaverTimer();
  });
  button.setPressMs(1000);
  button.attachLongPressStart([]() {
    resetTimer();
    press_start = millis();
    has_switched_wifi = false;
  });
  button.attachDuringLongPress(checkForHoldActions);

  control_callbacks_t callbacks;
  callbacks.startTimer = startTimer;
  callbacks.stopTimer = stopTimer;
  callbacks.resetTimer = resetTimer;
  callbacks.setBrightness = [&](uint8_t b) {
    state.brightness = b;
    display.setBrightness(state.brightness);
  };
  callbacks.setMode = [&](int8_t mode) {
    // Calling directly nextMode() async context will crash
    // the ESP when setting logo mode, not sure why
    async_next_mode = mode;
  };
  callbacks.resetScreensaverTimer = resetScreensaverTimer;
  callbacks.saveConfigAndReboot = [&]() {
    async_save_reboot = true;
  };
  // On ESP32, display need to be disabled during wifi activation
  displayUpdateEnable(false);
  initWifi(callbacks);
  displayUpdateEnable(true);

  showLogo();
  delay(3000);
  need_update = true;
}

void loop() {
  button.tick();

  if (async_save_reboot) {
    Serial.println("Async save config and reboot");
    // On ESP32, display need to be disabled during save config
    displayUpdateEnable(false);
    saveConfig();
    displayUpdateEnable(true);
    delay(1000);
    ESP.restart();
  }

  if (async_next_mode != state.cur_mode) {
    Serial.println("Async mode change");
    nextMode(async_next_mode);
  }

  if (state.cur_mode == MODE_INFO) {
    showInfo();
  } else if (state.cur_mode == MODE_LOGO) {
    showLogo();
  } else if (state.cur_mode == MODE_MESSAGE) {
    showMessage();
  } else {
    showTimer();
  }

  processServer();
}

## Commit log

2023-03-20 feat: update logo and implement timers
2023-03-20 fix: missing double click handler
    [main.cpp]
2023-03-20 chore: case placeholder
2023-03-21 docs: add wiring diagram
2023-03-21 feat: add wip case
    [case.scad]
2023-03-21 feat: continue case
    [case.scad]
2023-03-22 feat: add button holder
    [case.scad]
2023-03-22 fix: small fixes
    [case.scad]
2023-03-22 feat: add support
    [case.scad]
2023-03-23 feat: complete case
    [case.scad]
2023-03-23 feat: add test prints
    [case.scad]
2023-03-23 feat: add y split option and tweaks
    [case.scad]
2023-03-23 feat: improve tolerance
    [case.scad]
2023-03-23 feat: case tweaks
    [case.scad]
2023-03-24 fix: small case fix
    [case.scad]
2023-03-25 fix: case fixes
    [case.scad]
2023-03-25 chore: add missing tab
    [case.scad]
2023-03-26 chore: switch to 160Mhz
2023-03-28 feat: add screensaver timer
2023-03-28 feat: add screw option
    [case.scad]
2023-03-28 chore: remove cable holder
    [case.scad]
2023-03-28 chore: added free view option
    [case.scad]
2023-03-28 chore: fix comment
    [case.scad]
2023-03-28 chore: cleanup
    [case.scad]
2023-03-28 chore: update case pic
2023-03-28 chore: move case
2023-04-04 chore: fix case
    [case.scad]
2023-04-16 fix: make support tighter
    [case.scad]
2023-04-16 fix: button holder tab
    [case.scad]
2023-04-16 fix: extra spacing
    [case.scad]
2023-04-16 feat: add esp32 support
2023-04-16 fix: esp32 pin
2023-04-16 fix: esp32 timings
2023-04-17 fix: update screw dimensions
    [case.scad]
2023-04-18 fix: small case adjustments
    [case.scad]
2023-04-19 fix: tweak tolerance
    [case.scad]
2023-06-09 feat: add STL files for case
    [case_all_nosplit.stl, case_feet_and_button_lock.stl, case_left_part.stl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]
2023-06-09 docs: add 3d printing instructions
2023-06-09 docs: add assembly instructions
2023-06-09 docs: add link to assembly guide
2023-06-09 docs: add screws size
2024-01-07 fix: fix missing refactor
    [display.h]
2024-01-08 feat: add config reset
    [config.cpp, config.h]
2024-01-08 feat: add full reset
    [main.cpp]
2024-01-09 fix: format fs if fail to mount
    [config.cpp]
2024-01-09 fix: reduce display refresh for ESP8266 to fix DHCP issues
    [display.h]
2024-01-09 fix: regression with time reset
    [main.cpp]
2024-01-09 refactor: rework wifi integration
    [main.cpp, network.cpp]
2024-01-09 feat: add message mode and wifi switch
2024-01-11 fix: change refresh on esp8266 if wifi is on
    [display.h]
2024-01-11 fix: only update config wifi when needed
    [network.cpp]
2024-01-11 fix: cannot select 3rd timer
2024-01-11 fix: crash when setting logo through wifi
    [main.cpp, network.cpp]
2024-01-11 feat: add next mode button
2024-01-11 fix: delay mode change from wifi to fix crash
    [main.cpp]
2024-01-14 feat: use millis() for better timer precision
2024-01-14 fix: esp32 build
2024-01-15 fix: add async save and reboot to fix esp32 crash
    [main.cpp, network.cpp]
2024-01-15 chore: format fs on reset
    [config.cpp]
2024-01-15 refactor: use millis() everywhere
2024-02-01 fix: start always resetting timer
    [main.cpp]
